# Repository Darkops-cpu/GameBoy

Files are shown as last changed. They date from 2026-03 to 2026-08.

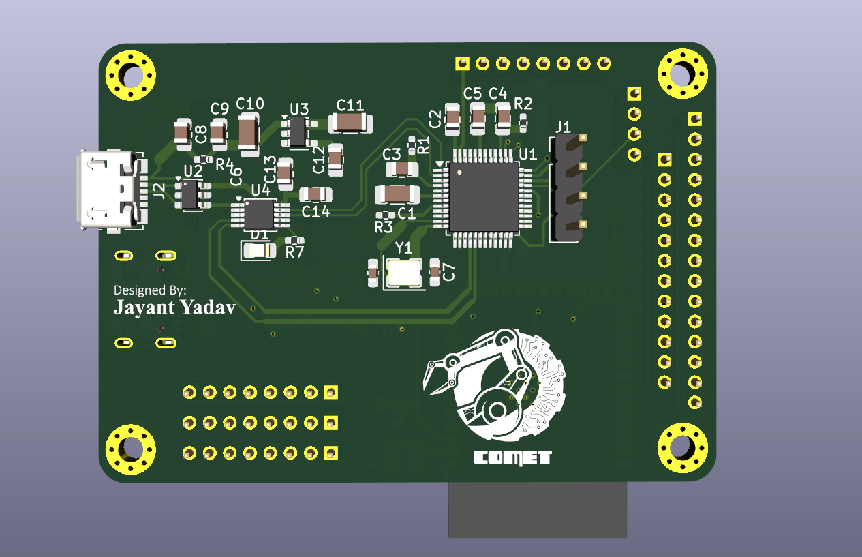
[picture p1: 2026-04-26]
PCB 3D/V2_front.png

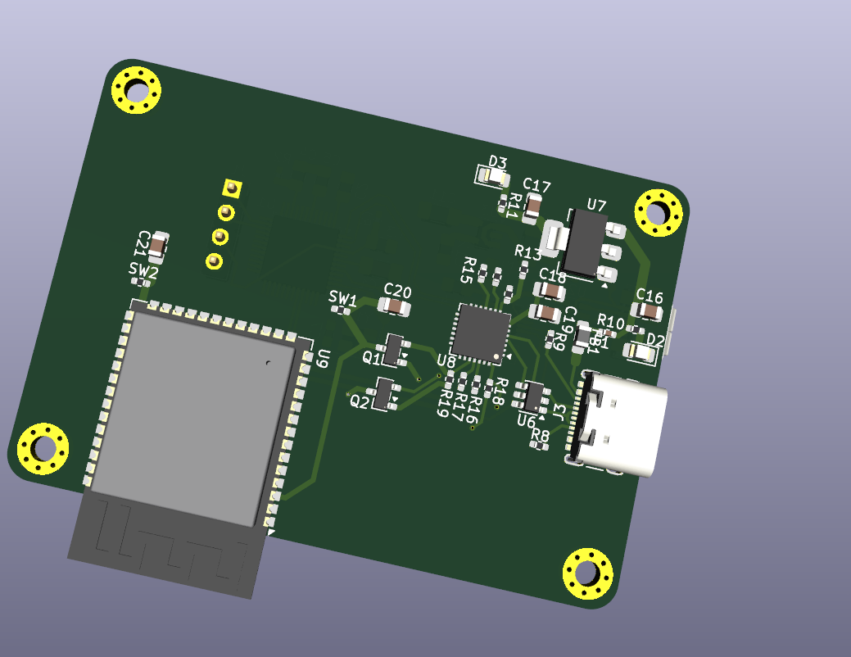
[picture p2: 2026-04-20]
PCB 3D/V1_front.png

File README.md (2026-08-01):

# HADES

 

**An embedded control brain for people who've outgrown the Arduino Uno.**

HADES is a dual-MCU prototyping and control board built around one idea: it is the *brain*, not the *muscle*. It runs your control loops and talks to the network — it does **not** carry motor current. Power for actuators lives on a separate, swappable **HADES shield**, so the brain stays clean, cool, and reusable across every robot you bolt it to.

> **Status:** 🚧 In active design. The architecture below is locked; hardware is in progress. Nothing here is manufactured yet — treat part-specific and pinout details marked _(TBD)_ as not-yet-final.

---

## Table of contents

- [Philosophy: brain, not muscle](#philosophy-brain-not-muscle)
- [Architecture](#architecture)
- [The HADES bus (the shield contract)](#the-hades-bus-the-shield-contract)
- [Planned features](#planned-features)
- [Power](#power)
- [Toolchain & programming](#toolchain--programming)
- [Repository structure](#repository-structure)
- [Getting started](#getting-started)
- [Roadmap](#roadmap)
- [Contributing & succession](#contributing--succession)
- [License](#license)
- [Origin](#origin)

---

## Philosophy: brain, not muscle

Most "do-everything" dev boards try to be the controller *and* the power stage on one PCB. That fights physics: high-current switching, motor back-EMF, heat, and ground bounce all land right next to the quiet analog front-end and the radio that make a good controller good.

HADES refuses that trade. The board sends control signals to the muscle and reads sensors back — nothing more. Actuator power is handled off-board, on a companion shield. The payoff:

- **Clean signals.** The analog front-end and the wireless radio live in a quiet neighborhood.
- **One brain, many muscles.** A small-servo shield today, a brushed-motor shield next term, a big BLDC shield later — same HADES underneath.
- **Failure isolation.** When someone stalls a motor and lets the smoke out of a driver, the cheap shield dies, not the brain.
- **Reusability.** The brain never needs a redesign to drive something new. That work moves to the shield, where it belongs.

## Architecture

HADES pairs a deterministic control MCU with a wireless / compute coprocessor, split by what each is good at.

```
                              HADES (the brain)
   +---------------------------------------------------------------+
   |                                                               |
   |   MSPM0G3507              UART              ESP32-S3 module    |
   |   (master)         <----------------->      (coprocessor)     |
   |   deterministic                              WiFi / BT /      |
   |   control          reset/boot GPIO --->      TinyML           |
   |                                                               |
   +------------------------------[ HADES bus ]--------------------+
                                       |
                                       |  signals + one clean supply
                                       |  (never raw battery / motor current)
                                       v
                              HADES shield (the muscle)
                          power stage / drivers / PDB
                                       |
                                       v
                              motors • servos • ESCs
```

| Role | Part | Handles |
|---|---|---|
| **Master** | TI MSPM0G3507 (Cortex-M0+, 80 MHz) | Deterministic, timing-critical work: control loops, motor PWM, sensor timing, CAN-FD |
| **Coprocessor** | Espressif ESP32-S3 (module) | Non-deterministic work: WiFi/BT, telemetry, OTA, on-device TinyML |

**Why the MSPM0G3507 for control:** two advanced control timers (motor PWM), two simultaneous-sampling 12-bit 4 Msps ADCs plus on-chip op-amps and comparators (a real current-sense front-end), CAN-FD, and the MATHACL trig accelerator to soften the M0+'s lack of a hardware FPU.

**Why the ESP32-S3 for comms/ML:** native USB (clean flashing), WiFi/BT, and vector/SIMD instructions that ESP-NN uses to accelerate TensorFlow Lite Micro — so it does the wireless *and* the on-device ML without a third chip.

The two talk over UART, and the MSPM0 drives the ESP32's `EN`/`IO0` lines so the master can reset or bootload the coprocessor (recovery + firmware updates).

## The HADES bus (the shield contract)

The interface between the brain and its shields is a **frozen, versioned contract** — the most important thing in the whole project. Freeze it well and HADES can rev to v4 while old shields still fit, and a junior can build a brand-new shield for a motor class nobody imagined.

The contract has two halves:

- **Electrical** — a fixed pinout: PWM/servo channels, CAN-FD, I²C, UART, GPIO/ADC breakouts, **one clean regulated supply into the brain**, and reserved lines for **current/voltage-sense telemetry coming back** from the shield (INA-over-I²C style). _(Exact pin assignment: TBD.)_
- **Mechanical** — a fixed board outline, mounting-hole geometry, and stack orientation, so the whole shield family is physically interchangeable. _(Footprint: TBD.)_

**The power boundary is the rule that makes this safe:** across the bus, only signals and one clean supply cross. Raw battery voltage and motor current **never** touch the brain — they stay on the shield.

The contract is versioned independently of the boards (e.g. `HADES bus v1`). A HADES revision and a shield revision each declare which bus version they speak, so compatibility is always unambiguous.

## Planned features

_(Design targets — subject to change until v1 is frozen.)_

- Dual-MCU: MSPM0G3507 master + ESP32-S3 coprocessor over UART
- CAN-FD transceiver + connector (multi-board robots; industry-relevant)
- 3-pin servo/PWM header bank off the MSPM0 advanced timers
- Quadrature encoder inputs on timer channels
- Onboard 6-axis IMU on SPI _(part TBD)_
- Qwiic / STEMMA-QT I²C connector for off-the-shelf sensors
- USB-C on the ESP32-S3 with auto-boot/reset (no button dance to flash)
- SWD header for the MSPM0
- Input protection (reverse-polarity + TVS), per-rail power LEDs, a user LED per MCU
- Test points on every rail and the inter-MCU UART
- Clearly silkscreened, 5 V-tolerant pins marked

## Power

HADES only regulates its *own* clean rails — the muscle's power supply lives on the shield.

- A single step-down stage takes the input down to a 5 V rail; a downstream stage produces 3.3 V for the logic.
- USB-C and the shield-supplied input are OR'd through a priority mux so sources never fight.
- A low-noise LDO (e.g. LT3045-class) generates a separate quiet analog rail for the MSPM0's op-amp/ADC front-end.

The board's own electronics sip very little, so the input battery is sized by whatever the *shield* drives, not by the brain.

## Toolchain & programming

**MSPM0G3507**
- Code Composer Studio + the MSPM0 SDK / DriverLib (or Zephyr / FreeRTOS)
- Flash/debug over SWD with an **XDS110** (e.g. an MSPM0 LaunchPad's onboard probe) or a **CMSIS-DAP** probe via OpenOCD (TI ships `mspm0.cfg`)
- ⚠️ **ST-Link is not supported** — its firmware is locked to STMicroelectronics silicon and will refuse the TI target.

**ESP32-S3**
- ESP-IDF (or Arduino-ESP32)
- Native USB-C — no external programmer needed

## Repository structure

```
hades/
├── hardware/          # KiCad project (schematics, layout, gerbers)
│   ├── hades-brain/   # the main board
│   └── shields/       # HADES shield designs
├── firmware/
│   ├── mspm0/         # master firmware
│   └── esp32s3/       # coprocessor firmware
├── bus-spec/          # the HADES bus contract (pinout + mechanical), versioned
├── docs/              # getting-started, guides, board notes
└── README.md
```

## Getting started

> ⏳ **Coming with the first hardware revision.** Once boards exist, this section will walk you from unboxing to "both MCUs alive, LED blinking, WiFi up" in under an hour. Until then, the design lives under `hardware/` and the interface under `bus-spec/`.

## Roadmap

- [ ] Freeze **HADES bus v1** (pinout + mechanical footprint)
- [ ] Complete the brain schematic and layout (KiCad, 4-layer)
- [ ] Small validation batch (~5 boards) — hand to real users, watch what breaks
- [ ] Getting-started guide + docs
- [ ] First **HADES shield** (matched to the actual motors juniors use)
- [ ] Wider production run

## Contributing & succession

HADES is built to outlive any single maintainer. The project is designed to be handed down: the current maintainer documents it, then passes it to an interested junior with full guidelines, and the cycle continues.

If you're picking this up:
- The **bus spec** is sacred — don't change a frozen bus version; publish a new one.
- Keep the KiCad sources buildable and the docs current; a board nobody can re-order or re-open is a dead board.
- Prefer parts that will still be stockable in two years.

## License

_(To be finalized — recommended split:)_
- **Hardware:** CERN-OHL-S or TAPR OHL
- **Firmware:** MIT or Apache-2.0
- **Documentation:** CC BY 4.0

## Origin

Originally developed at **IIIT Naya Raipur** to give students a genuine step up from the Arduino Uno + ESP32 combo — a real embedded control platform for robotics, maintained and passed down from one cohort to the next.

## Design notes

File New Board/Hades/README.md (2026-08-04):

# HADES

**A dual-MCU control brain for people who've outgrown the Arduino Uno + jumper-wire ESP32 combo.**

HADES is a control board built around one idea: it is the *brain*, not the *muscle*. It runs deterministic control loops and talks to the network — it does **not** carry motor current. Power for actuators lives on a separate, swappable **HADES shield**, so the brain stays clean, cool, and reusable across every robot it gets bolted to.

This repo is also the successor to an earlier, already-taped-out board (internally called **GameBoy**, see [`OLD Board/`](./OLD%20Board)) that proved the dual-MCU concept and is being folded into the brain/shield architecture described here.

> **Status:** 🚧 In active design. `New Board/Hades` is a fresh KiCad 9 project — USB-C input, ESD protection, and power-path parts are placed; the MSPM0/ESP32 core, the bus connector, and the rest of the schematic are not yet drawn. Nothing in this revision is manufactured. Everything marked _(TBD)_ below is not yet final. The **OLD Board** is a finished, previously-fabricated design (schematic + PCB renders present) and is the best current reference for "does this dual-MCU idea actually work."

---

## Table of contents

- [Philosophy: brain, not muscle](#philosophy-brain-not-muscle)
- [Architecture](#architecture)
- [The HADES bus (the shield contract)](#the-hades-bus-the-shield-contract)
- [Planned features](#planned-features)
- [Power](#power)
- [Toolchain & programming](#toolchain--programming)
- [Repository structure](#repository-structure)
- [Current status](#current-status)
- [Lineage: OLD Board (GameBoy) → HADES](#lineage-old-board-gameboy--hades)
- [Getting started](#getting-started)
- [Roadmap](#roadmap)
- [Why this project exists](#why-this-project-exists)
- [Contributing & succession](#contributing--succession)
- [License](#license)
- [Origin](#origin)

---

## Philosophy: brain, not muscle

Most "do-everything" dev boards try to be the controller *and* the power stage on one PCB. That fights physics: high-current switching, motor back-EMF, heat, and ground bounce all land right next to the quiet analog front-end and the radio that make a good controller good.

HADES refuses that trade. The board sends control signals to the muscle and reads sensors back — nothing more. Actuator power is handled off-board, on a companion shield. The payoff:

- **Clean signals.** The analog front-end and the wireless radio live in a quiet neighborhood.
- **One brain, many muscles.** A small-servo shield today, a brushed-motor shield next term, a big BLDC shield later — same HADES underneath.
- **Failure isolation.** When someone stalls a motor and lets the smoke out of a driver, the cheap shield dies, not the brain.
- **Reusability.** The brain never needs a redesign to drive something new. That work moves to the shield, where it belongs.

## Architecture

HADES pairs a deterministic control MCU with a wireless / compute coprocessor, split by what each is good at.

```
                              HADES (the brain)
   +---------------------------------------------------------------+
   |                                                               |
   |   MSPM0G3507              UART              ESP32-S3 module    |
   |   (master)         <----------------->      (coprocessor)     |
   |   deterministic                              WiFi / BT /      |
   |   control          reset/boot GPIO --->      TinyML           |
   |                                                               |
   +------------------------------[ HADES bus ]--------------------+
                                       |
                                       |  signals + one clean supply
                                       |  (never raw battery / motor current)
                                       v
                              HADES shield (the muscle)
                          power stage / drivers / PDB
                                       |
                                       v
                              motors • servos • ESCs
```

| Role | Part | Handles |
|---|---|---|
| **Master** | TI MSPM0G3507 (Cortex-M0+, 80 MHz) | Deterministic, timing-critical work: control loops, motor PWM, sensor timing, CAN-FD |
| **Coprocessor** | Espressif ESP32-S3 (module) | Non-deterministic work: WiFi/BT, telemetry, OTA, on-device TinyML |

**Why the MSPM0G3507 for control:** two advanced control timers (motor PWM), two simultaneous-sampling 12-bit 4 Msps ADCs plus on-chip op-amps and comparators (a real current-sense front-end), CAN-FD, and the MATHACL trig accelerator to soften the M0+'s lack of a hardware FPU.

**Why the ESP32-S3 for comms/ML:** native USB (clean flashing), WiFi/BT, and vector/SIMD instructions that ESP-NN uses to accelerate TensorFlow Lite Micro — so it does the wireless *and* the on-device ML without a third chip.

The two talk over UART, and the MSPM0 drives the ESP32's `EN`/`IO0` lines so the master can reset or bootload the coprocessor (recovery + firmware updates).

## The HADES bus (the shield contract)

The interface between the brain and its shields is a **frozen, versioned contract** — the most important thing in the whole project. Freeze it well and HADES can rev to v4 while old shields still fit, and a junior can build a brand-new shield for a motor class nobody imagined.

The contract has two halves:

- **Electrical** — a fixed pinout: PWM/servo channels, CAN-FD, I²C, UART, GPIO/ADC breakouts, **one clean regulated supply into the brain**, and reserved lines for **current/voltage-sense telemetry coming back** from the shield (INA-over-I²C style). _(Exact pin assignment: TBD.)_
- **Mechanical** — a fixed board outline, mounting-hole geometry, and stack orientation, so the whole shield family is physically interchangeable. _(Footprint: TBD.)_

**The power boundary is the rule that makes this safe:** across the bus, only signals and one clean supply cross. Raw battery voltage and motor current **never** touch the brain — they stay on the shield.

The contract is versioned independently of the boards (e.g. `HADES bus v1`). A HADES revision and a shield revision each declare which bus version they speak, so compatibility is always unambiguous.

## Planned features

_(Design targets — subject to change until v1 is frozen.)_

- Dual-MCU: MSPM0G3507 master + ESP32-S3 coprocessor over UART
- CAN-FD transceiver + connector (multi-board robots; industry-relevant)
- 3-pin servo/PWM header bank off the MSPM0 advanced timers
- Quadrature encoder inputs on timer channels
- Onboard 6-axis IMU on SPI _(part TBD)_
- Qwiic / STEMMA-QT I²C connector for off-the-shelf sensors
- USB-C on the ESP32-S3 with auto-boot/reset (no button dance to flash)
- SWD header for the MSPM0
- Input protection (reverse-polarity + TVS), per-rail power LEDs, a user LED per MCU
- Test points on every rail and the inter-MCU UART
- Clearly silkscreened, 5 V-tolerant pins marked

## Power

HADES only regulates its *own* clean rails — the muscle's power supply lives on the shield.

- A single step-down stage takes the input down to a 5 V rail; a downstream stage produces 3.3 V for the logic.
- USB-C and the shield-supplied input are OR'd through a priority mux so sources never fight.
- A low-noise LDO (e.g. LT3045-class) generates a separate quiet analog rail for the MSPM0's op-amp/ADC front-end.

The board's own electronics sip very little, so the input battery is sized by whatever the *shield* drives, not by the brain.

## Toolchain & programming

**MSPM0G3507**
- Code Composer Studio + the MSPM0 SDK / DriverLib (or Zephyr / FreeRTOS)
- Flash/debug over SWD with an **XDS110** (e.g. an MSPM0 LaunchPad's onboard probe) or a **CMSIS-DAP** probe via OpenOCD (TI ships `mspm0.cfg`)
- ⚠️ **ST-Link is not supported** — its firmware is locked to STMicroelectronics silicon and will refuse the TI target.

**ESP32-S3**
- ESP-IDF (or Arduino-ESP32)
- Native USB-C — no external programmer needed

## Repository structure

This is what's actually in the repo today — not the target layout yet (see [Roadmap](#roadmap) for the reorganization into `hardware/` / `firmware/` / `bus-spec/` once the brain/shield split is real):

```
HADES/
├── New Board/
│   └── Hades/                    # current KiCad 9 project — the HADES "brain" board
│       ├── Hades.kicad_pro
│       ├── Hades.kicad_sch       # schematic (in progress — power in, MCUs not yet placed)
│       ├── Hades.kicad_pcb       # 2-layer layout, early
│       ├── Hades-backups/        # KiCad auto-backups (timestamped .zip snapshots)
│       └── README.md
├── OLD Board/                    # predecessor design, "GameBoy" — finished, previously fabricated
│   ├── README.md                 # full spec sheet + design-decision rationale
│   ├── Schematic/                # V1.0 – V1.3 schematic PDFs
│   ├── Docs/                     # V1.0 – V1.3 per-revision changelogs
│   ├── PCB 3D/                   # rendered board images (front/back, V1 & V2)
│   └── Reference/                # ESP32/MSPM0 datasheets + design references
└── README.md                     # this file
```

## Current status

| Track | State |
|---|---|
| **OLD Board (GameBoy)** — architecture proof | ✅ Schematic finalized through V1.3, PCB rendered, previously fabricated |
| **New Board (HADES brain)** — schematic | 🔄 Power input (USB-C, ESD protection) placed; MSPM0G3507 + ESP32-S3 core not yet drawn |
| **New Board (HADES brain)** — layout | 🔄 2-layer board started; routing pending schematic completion |
| **HADES bus (shield contract)** | ⏳ Not yet frozen — pinout and mechanical footprint TBD |
| **HADES shield** | ⏳ Not started |
| **Firmware (either MCU)** | ⏳ Not started — waiting on hardware |

## Lineage: OLD Board (GameBoy) → HADES

The `OLD Board/` design (codename **GameBoy**, no relation to Nintendo) is where the dual-MCU idea — TI **MSPM0G3507** as the deterministic master, **ESP32-S3-WROOM-1** as the wireless/compute coprocessor over UART — was designed, schematic-captured, and taken through four documented revisions:

| Rev | Change | Why |
|---|---|---|
| V1.0 | Single MCU (MSPM0G3507) + CH340E debug UART + LIS2DH accelerometer | Baseline: get the master MCU alive and talking |
| V1.1 | Added ESP32-S3-WROOM-1 coprocessor, CP2102N + auto-boot circuit, USB-C | Wireless/compute half of the architecture, flashable without a button dance |
| V1.2 | Added TP4056 Li-ion charging + BJT/MOSFET power-path switching | Untethered, battery-capable operation |
| V1.3 | **Removed** the V1.2 battery circuitry | Simplify the power path for the current build phase — a real "found the hard way, fixed" cycle, not just additive changes |

That revision history is the same succession pattern this repo is designed to keep running: something breaks or turns out unnecessary, the next revision documents why and fixes it, and the fix is traceable in `OLD Board/Docs/`.

`New Board/Hades` is the next link in that chain — it keeps the dual-MCU pairing but re-architects around the **brain/shield split** described above, instead of putting motor drive and battery management on the same board as the control MCU.

## Getting started

> ⏳ **Coming with the first hardware revision.** Once brain boards exist, this section will walk you from unboxing to "both MCUs alive, LED blinking, WiFi up" in under an hour, with no hand-wired jumper diagram involved. Until then:
> - To see the dual-MCU architecture working end-to-end today, read [`OLD Board/README.md`](./OLD%20Board/README.md) and the V1.0–V1.3 docs in [`OLD Board/Docs/`](./OLD%20Board/Docs).
> - To follow or contribute to the current board, open [`New Board/Hades/Hades.kicad_sch`](./New%20Board/Hades/Hades.kicad_sch) in KiCad 9.

## Roadmap

- [ ] Complete the HADES brain schematic (MSPM0G3507 + ESP32-S3 core, current-sense front-end, CAN-FD transceiver)
- [ ] Freeze **HADES bus v1** (pinout + mechanical footprint)
- [ ] Finish the 4-layer brain PCB layout
- [ ] Small validation batch (~5 boards) — hand to real users, watch what breaks
- [ ] Reorganize the repo into `hardware/` / `firmware/` / `bus-spec/` / `docs/` once the brain/shield split is fabricated
- [ ] Getting-started guide + docs (the "forty minutes to a sweeping servo" experience)
- [ ] First **HADES shield** (matched to the actual motors used on club robots)
- [ ] Wider production run + institutional handoff to a junior maintainer

## Why this project exists

The measure of success here isn't the PCB — it's what happens after it. HADES is meant to stop being "someone's project" and become "the board": something a first-year reaches for in week three without a wiring diagram, something the club's competition robots run on under real deadline pressure, something that keeps getting revised by people who never met the original designer.

Concretely, that means:
- **Faster than the breadboard, not just different from it.** If reaching for a HADES isn't the obviously easier choice next to a fistful of dupont wires, the board hasn't earned its place yet.
- **Survives contact with students and with robots.** Bench demos are cheap; a board holding a current-sense loop through a stalled motor for real, under competition deadline, is the actual test.
- **The revision chain has to turn without the original designer.** Rev 1 will have a quirk someone finds the hard way (the OLD Board's V1.0→V1.3 history is exactly that pattern already). What matters is whether rev 2 gets fixed and shipped by someone else, using docs good enough that they didn't need to ask.

Almost every student hardware project dies on two things: **documentation nobody wrote** and **a handoff that never happened**. Everything in [Contributing & succession](#contributing--succession) below exists to clear those two bars on purpose, rather than assuming they'll clear themselves.

## Contributing & succession

HADES is built to outlive any single maintainer. The project is designed to be handed down: the current maintainer documents it, then passes it to an interested junior with full context, and the cycle continues — the same way `OLD Board/Docs/V1.0.md` through `V1.3.md` already document what changed and why at each step.

If you're picking this up:
- The **bus spec** is sacred — don't change a frozen bus version; publish a new one.
- Keep the KiCad sources buildable and the docs current; a board nobody can re-order or re-open is a dead board.
- Document *why*, not just *what* — follow the pattern in `OLD Board/Docs/`: what changed, and the reason, per revision.
- Prefer parts that will still be stockable in two years.
- If you're the one stepping back, name your successor before you go quiet — a maintainer chain with a gap in it is how projects die.

## License

_(To be finalized — recommended split:)_
- **Hardware:** CERN-OHL-S or TAPR OHL
- **Firmware:** MIT or Apache-2.0
- **Documentation:** CC BY 4.0

## Origin

Originally developed at **IIIT Naya Raipur** to give students a genuine step up from the Arduino Uno + ESP32 combo — a real embedded control platform for robotics, maintained and passed down from one cohort to the next.

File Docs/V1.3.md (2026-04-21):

# Schematic V1.3 Documentation

## 1. Overview
The V1.3 board keeps the dual-processor architecture (MSPM0G3507SPTR and ESP32-S3 WROOM 1) while removing the battery charging and battery switching/load-sharing circuitry introduced previously. This revision returns the design to a wired-power-only approach and simplifies the power path for the current build phase.

## 2. Core Components
The main processing and connectivity elements remain unchanged:
- **Primary Microcontroller (MCU):** Texas Instruments MSPM0G3507SPTR.
- **Secondary Microcontroller:** **ESP32-S3 WROOM 1** module.
- **Inter-Processor Bridge:** Communication bridge between MSPM0 and ESP32 is established.
- **USB-to-UART Controller:** CP2102N for serial communication and ESP32 auto-boot support.
- **Accelerometer:** LIS2DH for motion sensing.

## 3. Power Subsystem (Revision Change)
The V1.3 power subsystem removes all battery-management-specific blocks:
- **Removed:** Li-ion charging circuit.
- **Removed:** Battery switching/load-sharing circuit.
- **System Power:** Board is powered from USB input and regulated to 3.3V through the **LM1117** linear regulator.

## 4. Interfaces and Connectors
- **USB Interface:** USB-C receptacle for power and data.
- **ESP32 Auto-Boot:** DTR/RTS auto-boot circuitry retained.
- **Battery Interface:** No battery charging or battery switching path in this revision.

## 5. Status, Flashing, and Errata
- **Schematic Status:** Finalized for PCB plotting.
- **Flashing:**
	- ESP32-S3 programs via USB-C using the CP2102N auto-boot circuit.
	- MSPM0 requires an **ST-Link** (or compatible SWD programmer).
- **Errata:** No known issues documented for V1.3 at this time.

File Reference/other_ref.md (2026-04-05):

## Other References

- Stack Exchange: [link](https://electronics.stackexchange.com/questions/21570/switch-between-battery-and-usb-power)
- GitHub: [link](https://github.com/alltheworld/tp4056)
- Espressif Guidelines: [link](https://docs.espressif.com/projects/esp-hardware-design-guidelines/en/latest/esp32/pcb-layout-design.html)

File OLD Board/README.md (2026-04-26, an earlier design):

# GameBoy 🎮


A custom dual-processor embedded development platform built around the **Texas Instruments MSPM0G3507** and the **Espressif ESP32-S3-WROOM-1**, designed for IoT connectivity, sensor data collection, and general-purpose prototyping.

> Designed from scratch in KiCad 9.0.8 — schematic complete, PCB layout in progress.

## Project Summary

GameBoy is a dual-MCU embedded platform that combines the real-time control of the MSPM0G3507 with the wireless connectivity of the ESP32-S3-WROOM-1. The board uses a dedicated UART bridge between the two processors, includes onboard programming and debug interfaces, and is being developed as a compact hardware platform for prototyping, sensor integration, and IoT-oriented experiments. The current revision is a 4-layer board to support cleaner routing, better power integrity, and improved overall layout density.

---

## Overview

GameBoy is a compact, battery-capable development board that pairs the real-time processing power of the MSPM0G3507 with the WiFi and Bluetooth capabilities of the ESP32-S3, communicating over a dedicated UART bus. The goal is a flexible platform that can be adapted across a wide range of embedded applications without redesigning hardware each time.

This is not a hobbyist shield or a breakout board. Every subsystem — power architecture, programming interfaces, peripheral connections, and RF considerations — has been designed with deliberate engineering decisions documented below.

---

## Hardware Specifications

| Parameter | Details |
|---|---|
| Main MCU | TI MSPM0G3507SPTR — ARM Cortex-M0+, 80MHz, 128KB Flash, 32KB SRAM |
| Co-processor | Espressif ESP32-S3-WROOM-1 — Xtensa LX7, WiFi 802.11 b/g/n, BLE 5.0 |
| Inter-processor bus | UART (MSPM0 UART1 ↔ ESP32-S3 UART0) |
| Supply voltage | 5V via USB / Single-cell Li-ion (18650) |
| System voltage | 3.3V (SPX3819M5 LDO) |
| Battery charging | MCP73831 linear charger — 300mA via USB-C |
| Power path | LM66200DRLR ideal diode — automatic USB / battery switchover |
| Crystal | 8MHz external oscillator for MSPM0 |
| PCB layers | 4-layer |
| EDA tool | KiCad 9.0.8 |

---

## Block Diagram

```
                        ┌─────────────────────────────────────┐
                        │           Power Section             │
  USB-C (5V) ──────────►│ MCP73831 ──► 18650 Li-ion           │
                        │ LM66200 (auto power path switching)  │
                        │ SPX3819M5 LDO ──► 3.3V rail         │
                        └────────────────┬────────────────────┘
                                         │ 3.3V
                  ┌──────────────────────┼──────────────────────┐
                  │                      │                      │
         ┌────────▼────────┐    ┌────────▼────────┐   ┌────────▼────────┐
         │  MSPM0G3507     │    │  ESP32-S3        │   │  LIS2DH12       │
         │  Main processor │◄──►│  WiFi + BT       │   │  Accelerometer  │
         │  SWD via STLink │UART│  CP2102N + auto  │   │  SPI            │
         │  UART0 debug    │    │  boot circuit    │   └─────────────────┘
         └────────┬────────┘    └────────┬─────────┘
                  │                      │
         ┌────────▼────────┐    ┌────────▼─────────┐
         │  GPIO Bank A    │    │  GPIO Bank B      │
         │  MSPM0 pins     │    │  ESP32-S3 pins    │
         └─────────────────┘    └──────────────────┘
```

---

## Subsystems

### Main MCU — MSPM0G3507
- ARM Cortex-M0+ running at up to 80MHz
- Programmed via SWD using STLink V2 through a 4-pin header (SWCLK, SWDIO, NRST, GND)
- UART0 exposed via onboard CH340E for debug output
- 4 UART peripherals available — UART1 dedicated to ESP32-S3 communication
- Full GPIO bank broken out to 2.54mm headers

### Co-processor — ESP32-S3-WROOM-1
- Handles all WiFi and Bluetooth stack operations
- Programmed independently via dedicated USB-C port and CP2102N USB-UART bridge
- Auto-boot circuit (two MMBT2222A NPN transistors) — no manual button pressing required to flash
- Manual reset (SW1) and boot (SW2) buttons included as fallback
- IO19 and IO20 (native USB D+/D−) left available for future USB device applications
- GPIO bank broken out to 2.54mm headers

### Power Architecture
- **LM66200DRLR** ideal diode controller manages automatic switchover between USB-C (5V) and Li-ion battery (3.7V) — USB always takes priority when present
- **MCP73831** linear charger handles single-cell Li-ion charging at 300mA (set via 3.3K RPROG resistor), powered from the ESP32-S3 USB-C port
- **SPX3819M5** 500mA LDO regulates system 3.3V rail
- Two 18650 cells in parallel supported — no balancing circuit required for parallel configuration
- Battery voltage monitoring via MSPM0 ADC through resistor divider

### Programming Interfaces
| Target | Method | Connector |
|---|---|---|
| MSPM0G3507 firmware | STLink V2 via SWD | 4-pin header |
| MSPM0 debug UART | CH340E via USB Micro | USB Micro B |
| ESP32-S3 firmware | CP2102N + auto-boot via USB-C | USB-C |

### Peripheral — LIS2DH12 Accelerometer
- ST MEMS 3-axis accelerometer
- Connected via SPI to MSPM0G3507
- INT1 and INT2 interrupt lines routed to MSPM0 GPIO

---

## Repository Structure

```
GameBoy/
├── Schematic/
│   ├── V1.0.pdf          # Main MCU schematic sheet
│   ├── V1.0.pdf         # Main MCU schematic sheet + ESP32-S3 subcircuit sheet
├── Docs/
│   └── esp32_devkitc_v4-sch.pdf        # ESP32 Device schematic reference
|   └── mspm0g3507_Ti.pdf       # MSPM0 Instruction Manual
├── Docs/
│   ├── V1.0.md/                     # upadtes implemented in schematic one
│   └── V2.0.md/                     # updates implemented in schematic two
└── README.md
```

---

## Design Decisions

A few non-obvious decisions made during the design process, documented for anyone reading the schematic.

**Why MSPM0G3507 and not STM32?**
TI's MSPM0 series offers a competitive Cortex-M0+ core with a generous free tier on Code Composer Studio and strong documentation. The LQFP-48 package is hand-solderable and the peripheral set covers everything needed for this platform.

**Why ESP32-S3 and not classic ESP32?**
The S3 supports BLE 5.0 and has a native USB peripheral on IO19/IO20, keeping future options open. The WROOM-1 module handles the RF design, antenna matching, and FCC certification — removing the most complex part of ESP32 integration from the custom PCB.

**Why CP2102N for ESP32 programming instead of using native USB?**
Native USB on IO19/IO20 works, but is dependent on the ESP32-S3 firmware being functional. A dedicated CP2102N with auto-boot circuit means the programming interface is always independent of firmware state — critical on a prototyping board where firmware is frequently broken during development.

**Why 4-layer PCB?**
The 4-layer stackup improves power distribution, signal routing, and ground integrity for the dual-MCU design. It also gives cleaner separation between noisy digital sections, the ESP32-S3 RF area, and the power subsystem while making the board easier to route at the current feature density.

**Why LM66200 for power path instead of a discrete P-FET?**
The LM66200 is an ideal diode controller with 40mΩ on-resistance, automatic priority switching, reverse current blocking, and 1.32µA quiescent current — all in one IC with no external switching logic required. The discrete P-FET approach requires careful gate biasing and does not block reverse current.

---

## Current Status

| Milestone | Status |
|---|---|
| System architecture | ✅ Complete |
| MSPM0 schematic | ✅ Complete |
| ESP32-S3 schematic | ✅ Complete |
| Power section schematic | ✅ Complete |
| PCB layout | 🔄 In progress |
| Fabrication | ⏳ Pending layout |
| Firmware — MSPM0 | ⏳ Pending hardware |
| Firmware — ESP32-S3 | ⏳ Pending hardware |

---

## Planned Features (Future Revisions)

- Motor driver header with PWM breakout from MSPM0 timers
- QWIIC / Stemma QT I2C connector for plug-and-play sensor expansion
- USB-C PD negotiation for faster battery charging
- Onboard LiPo fuel gauge IC for accurate battery percentage reporting
- KiCad PCB layout with JLCPCB-compatible BOM and CPL files

---

## Tools Used

- **KiCad 9.0.8** — schematic capture and PCB layout
- **Code Composer Studio** — MSPM0 firmware development
- **ESP-IDF** — ESP32-S3 firmware development
- **LCSC** — component sourcing

---

## Author

Darkops-CPU (Jayant Yadav)

---

*The name GameBoy has no relation to Nintendo's product. It is an arbitrary project codename.*

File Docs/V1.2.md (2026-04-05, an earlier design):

# Schematic V1.2 Documentation

## 1. Overview
The V1.2 board builds upon the dual-processor architecture of V1.1 (MSPM0G3507SPTR and ESP32-S3 WROOM 1) by introducing full battery power management. This revision features a dedicated Li-ion battery charging and discharging circuit, alongside an automatic power switching mechanism to allow the board to function seamlessly when plugged into USB or running directly off the battery. The schematic is finalized and ready for PCB plotting.

## 2. Core Components
The primary processing and connectivity components are carried over from V1.1:
- **Primary Microcontroller (MCU):** Texas Instruments MSPM0G3507SPTR.
- **Secondary Microcontroller:** **ESP32-S3 WROOM 1** module.
- **Inter-Processor Bridge:** The bridge between the MSPM0 and ESP32 has been established.
- **USB-to-UART Controller:** CP2102N for serial communication and debugging with auto-boot support for the ESP32.
- **Accelerometer:** LIS2DH for motion sensing.

## 3. Power Subsystem (Major Update)
The V1.2 revision completely revamps the power subsystem to support untethered operation:
- **Battery Specifications:** Designed for a standard Li-ion battery.
- **Charging Circuit:** Utilizes a standard TP4056-based charging circuit to safely charge the Li-ion battery when USB-C is connected.
- **Power Switching/Load Sharing:** An automatic power-path switching circuit has been implemented using a combination of two BJTs (NPN and PNP) and one P-Channel MOSFET. This ensures that when the USB-C is connected, the system is powered directly from USB while the battery charges, and when disconnected, it transitions smoothly to battery power without interrupting the processors.
- **System Power:** The board continues to use the **LM1117** linear regulator (carried from V1.1) to provide a stable 3.3V supply to the MCUs from either the battery or USB source.

## 4. Interfaces and Connectors
- **Battery Connector:** A terminal block has been added to securely connect the Li-ion battery to the power management circuit.
- **USB Interface:** USB-C receptacle for data and power delivery/charging.
- **ESP32 Auto-Boot:** Retains the DTR/RTS auto-boot circuitry for the ESP32-S3.

## 5. Known Issues, Flashing, and Errata
- **Flashing:** 
  - ESP32-S3 programs via the USB-C port utilizing the CP2102N auto-boot circuit.
  - MSPM0 still requires an **ST-Link** (or compatible SWD programmer) for flashing.
- **Errata:** There are currently no known issues or errata documented for the V1.2 release.

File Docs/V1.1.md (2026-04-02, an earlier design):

# Schematic V1.1 Documentation



## 1. Overview
The V1.1 board builds upon the initial design by introducing a dual-processor architecture. It retains the core processing capabilities while adding an ESP32-S3 WROOM 1 module to handle advanced connectivity and secondary processing tasks.

## 2. Core Components
Significant updates have been made to the component selection in this revision:
- **Primary/Secondary Microcontrollers:** 
  - The board now features an **ESP32-S3 WROOM 1** module as a secondary processor for enhanced capabilities and wireless communication.
  - (Assuming retention of the original MSPM0G3507SPTR main MCU and LIS2DH accelerometer from V1.0, unless otherwise replaced).
- **USB-to-UART Controller:** Upgraded to the **CP2102N**, providing robust serial communication and debugging, specifically supporting the new ESP32 integration.
- **Clocking:** Relevant crystal oscillators for both MCUs.

## 3. Power Subsystem
The power architecture has been modernized for better compatibility and current delivery:
- **Power Input:** Upgraded to **USB-C** for both power delivery and data connection.
- **Voltage Regulation (LDO):** The primary 3.3V power supply is now driven by an **LM1117** linear regulator to meet the increased current demands of the ESP32-S3.

## 4. Interfaces, Connectors, and Boot Logic
While external displays or heavy peripherals are still omitted in this revision, crucial interface updates have been made:
- **ESP32 Auto-Boot:** The integration of an auto-boot circuit for the ESP32-S3 has been enabled, allowing for seamless programming and resetting without manual button presses via the CP2102N UART lines (DTR/RTS).
- **USB Interface:** Modern USB-C receptacle replaces the older Micro USB.

## 5. Known Issues, Flashing, and Errata
- **Flashing the ESP32-S3:** The auto-boot circuitry handles putting the ESP32-S3 into the correct boot mode automatically during programming.
- **Flashing the MSPM0:** The original requirement of using an **ST-Link** (or compatible SWD programmer) via the SWD interface remains unchanged from V1.0.
- **Errata:** There are currently no known bugs or errata documented for the V1.1 release.

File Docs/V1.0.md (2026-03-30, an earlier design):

# Schematic V1.0 Documentation



## 1. Overview
The V1.0 board serves as the main processor module for the overarching design. It handles the core logic, processing, and acts as the central hub before integration with the rest of the hardware components.

## 2. Core Components
The board integrates several key components to achieve its processing and connectivity goals:
- **Main Microcontroller (MCU):** Texas Instruments `MSPM0G3507SPTR` in a 48-LQFP package.
- **USB-to-UART Controller:** `CH340E` for serial communication and debugging.
- **Accelerometer:** `LIS2DH` for motion sensing and orientation detection.
- **Clock:** 8MHz external crystal oscillator for precise timing.

## 3. Power Subsystem
The power architecture is designed to step down a standard 5V USB input to the 3.3V logic level required by the MCU and peripherals.
- **Power Input:** Micro USB (5V source).
- **ESD Protection:** `USBLC6-2SC6` on the USB D+/D- lines to protect against electrostatic discharge.
- **Voltage Regulation (LDO):** `SPX3819M5-L-3-3` Low Dropout Regulator to provide a stable 3.3V supply to the system.

## 4. Interfaces and Connectors
As of V1.0, the primary interface is the Micro USB port for power and UART communication. Other external user interfaces (such as screens or buttons) are currently omitted on this revision and will be included once the board is fully integrated into the larger chassis/design.

## 5. Known Issues, Flashing, and Errata
> **Warning: Programming Interface**
> The only significant caveat in this revision involves the programming process. If not done correctly, the board will fail to program.
> - An **ST-Link** (or compatible SWD programmer) is required to flash the `MSPM0G3507SPTR` microcontroller.
> - Ensure proper SWD (Serial Wire Debug) connections (SWDIO, SWCLK, GND, 3V3) are made from the ST-Link to the corresponding pins/pads on the board.

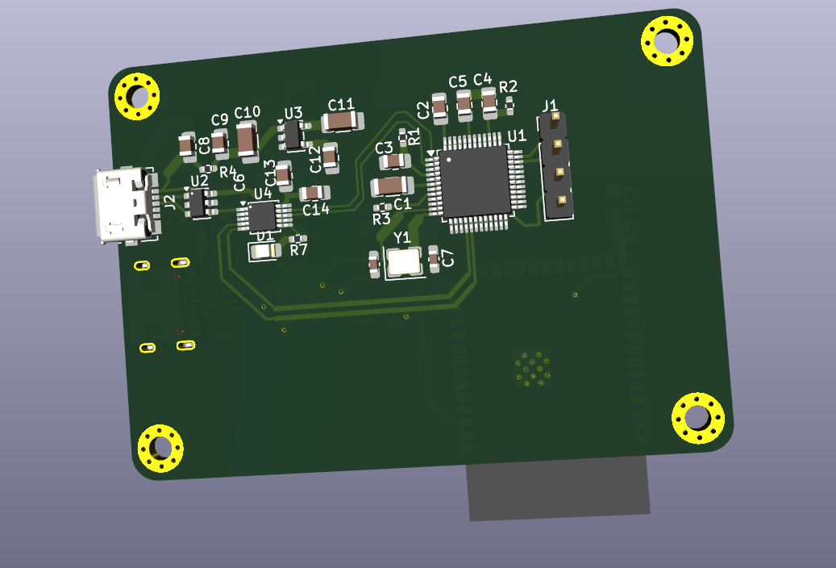
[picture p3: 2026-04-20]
PCB 3D/V1_back.png

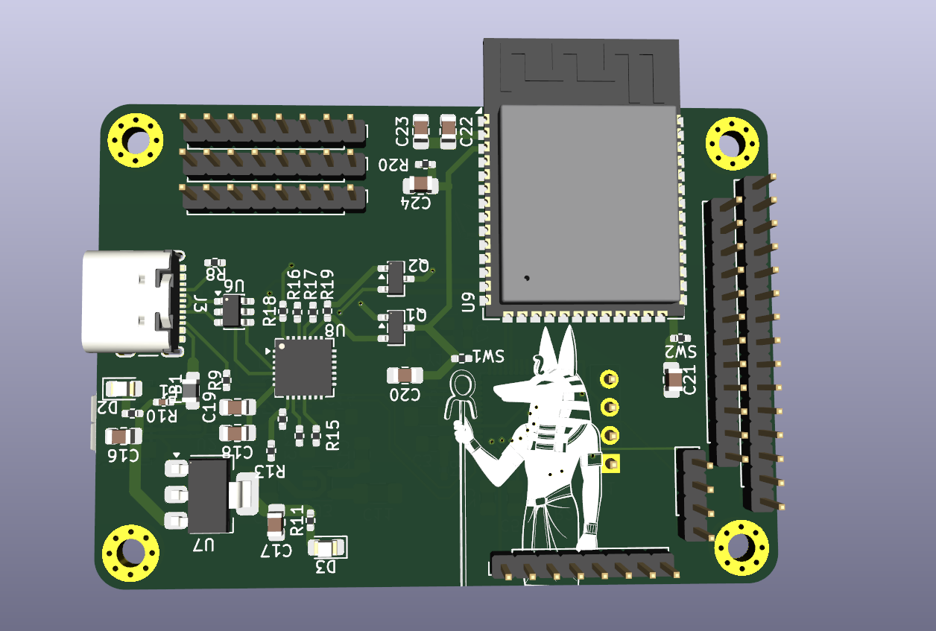
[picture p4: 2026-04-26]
PCB 3D/V2_back.png

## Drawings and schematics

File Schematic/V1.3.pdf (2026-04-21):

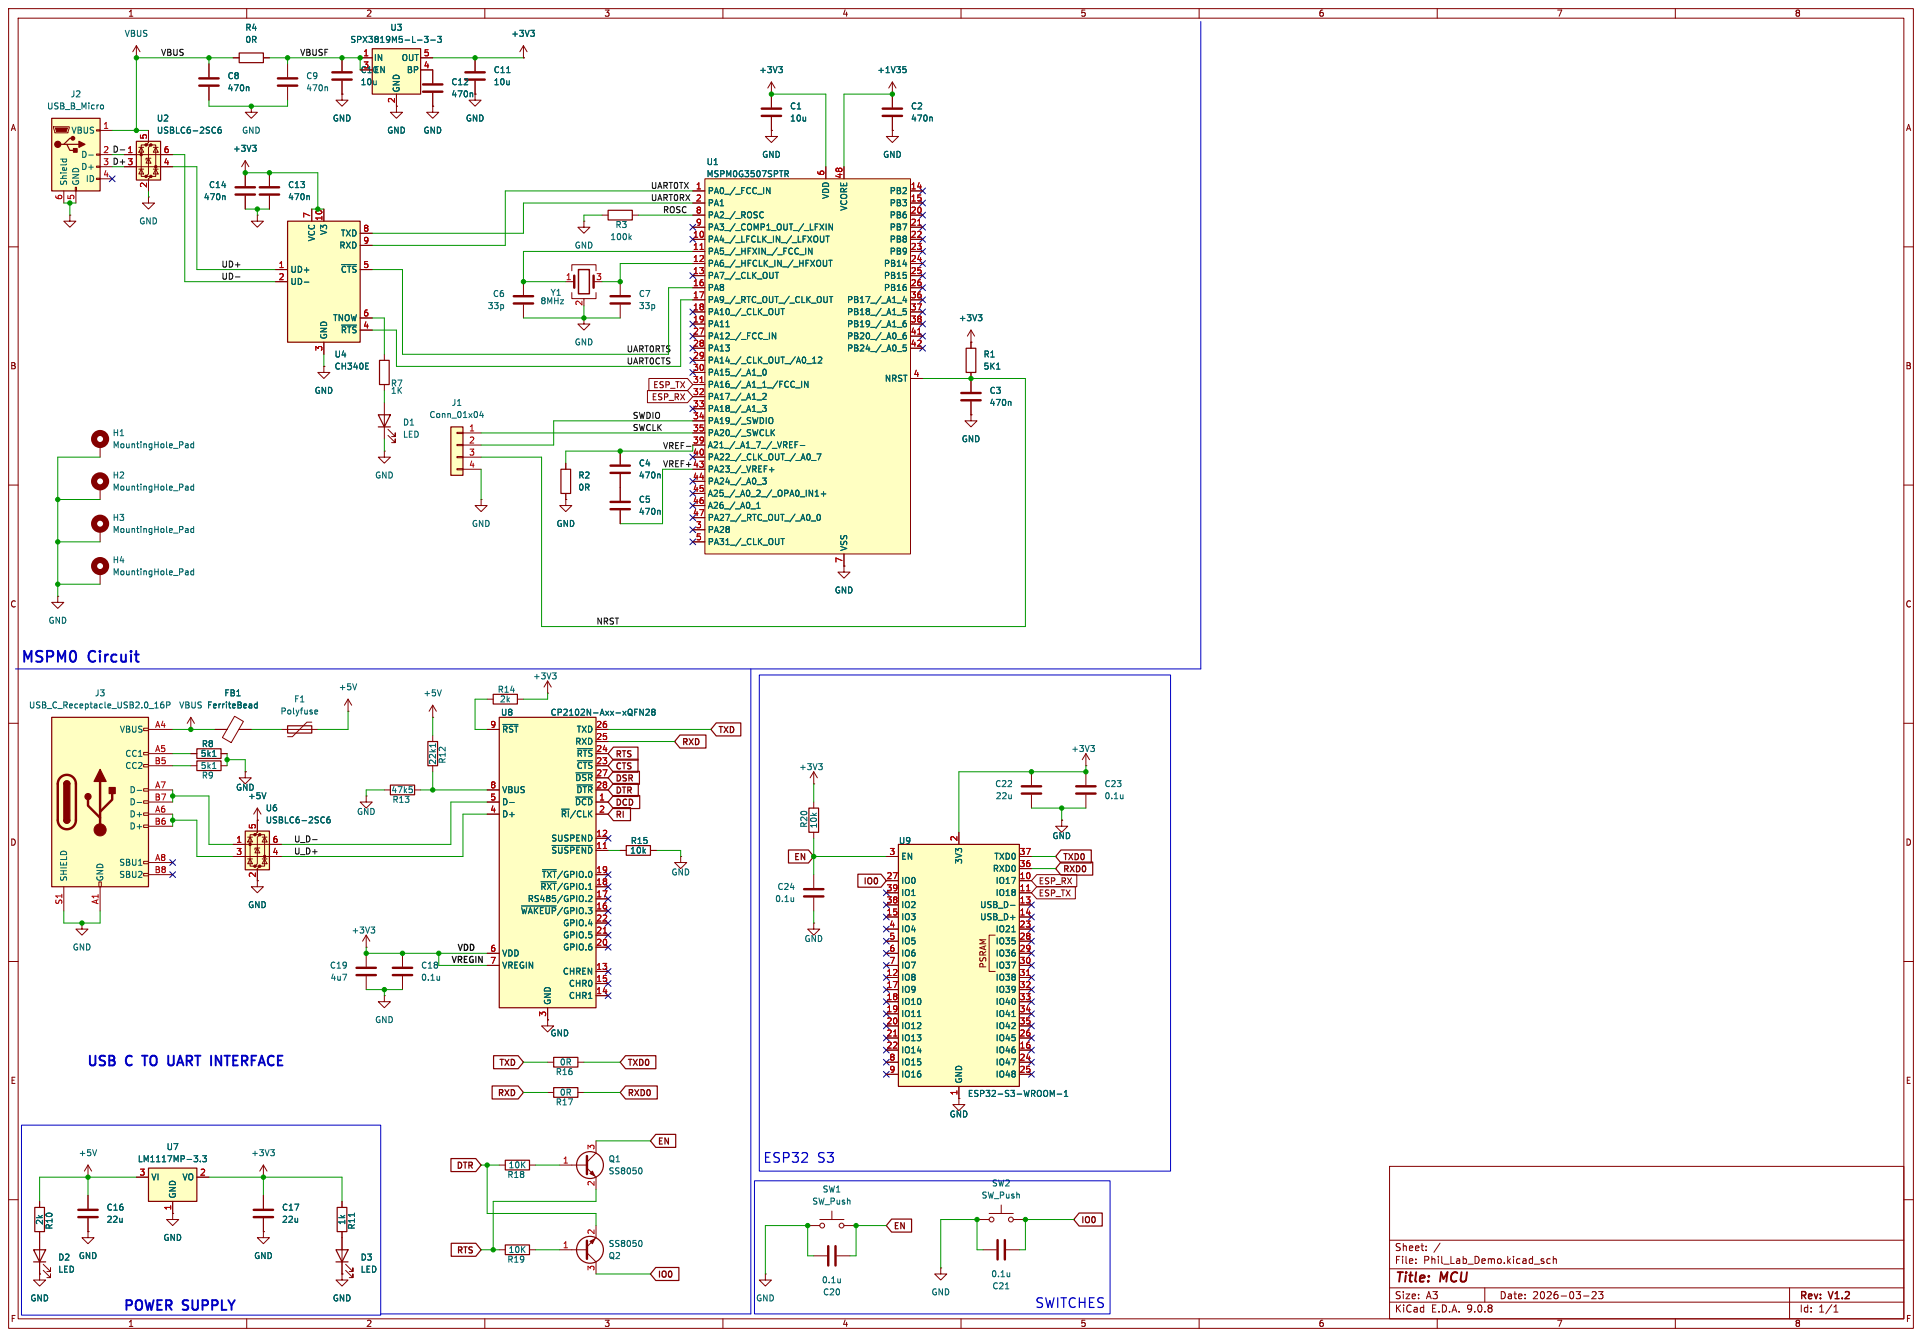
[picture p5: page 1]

USB C TO UART INTERFACE

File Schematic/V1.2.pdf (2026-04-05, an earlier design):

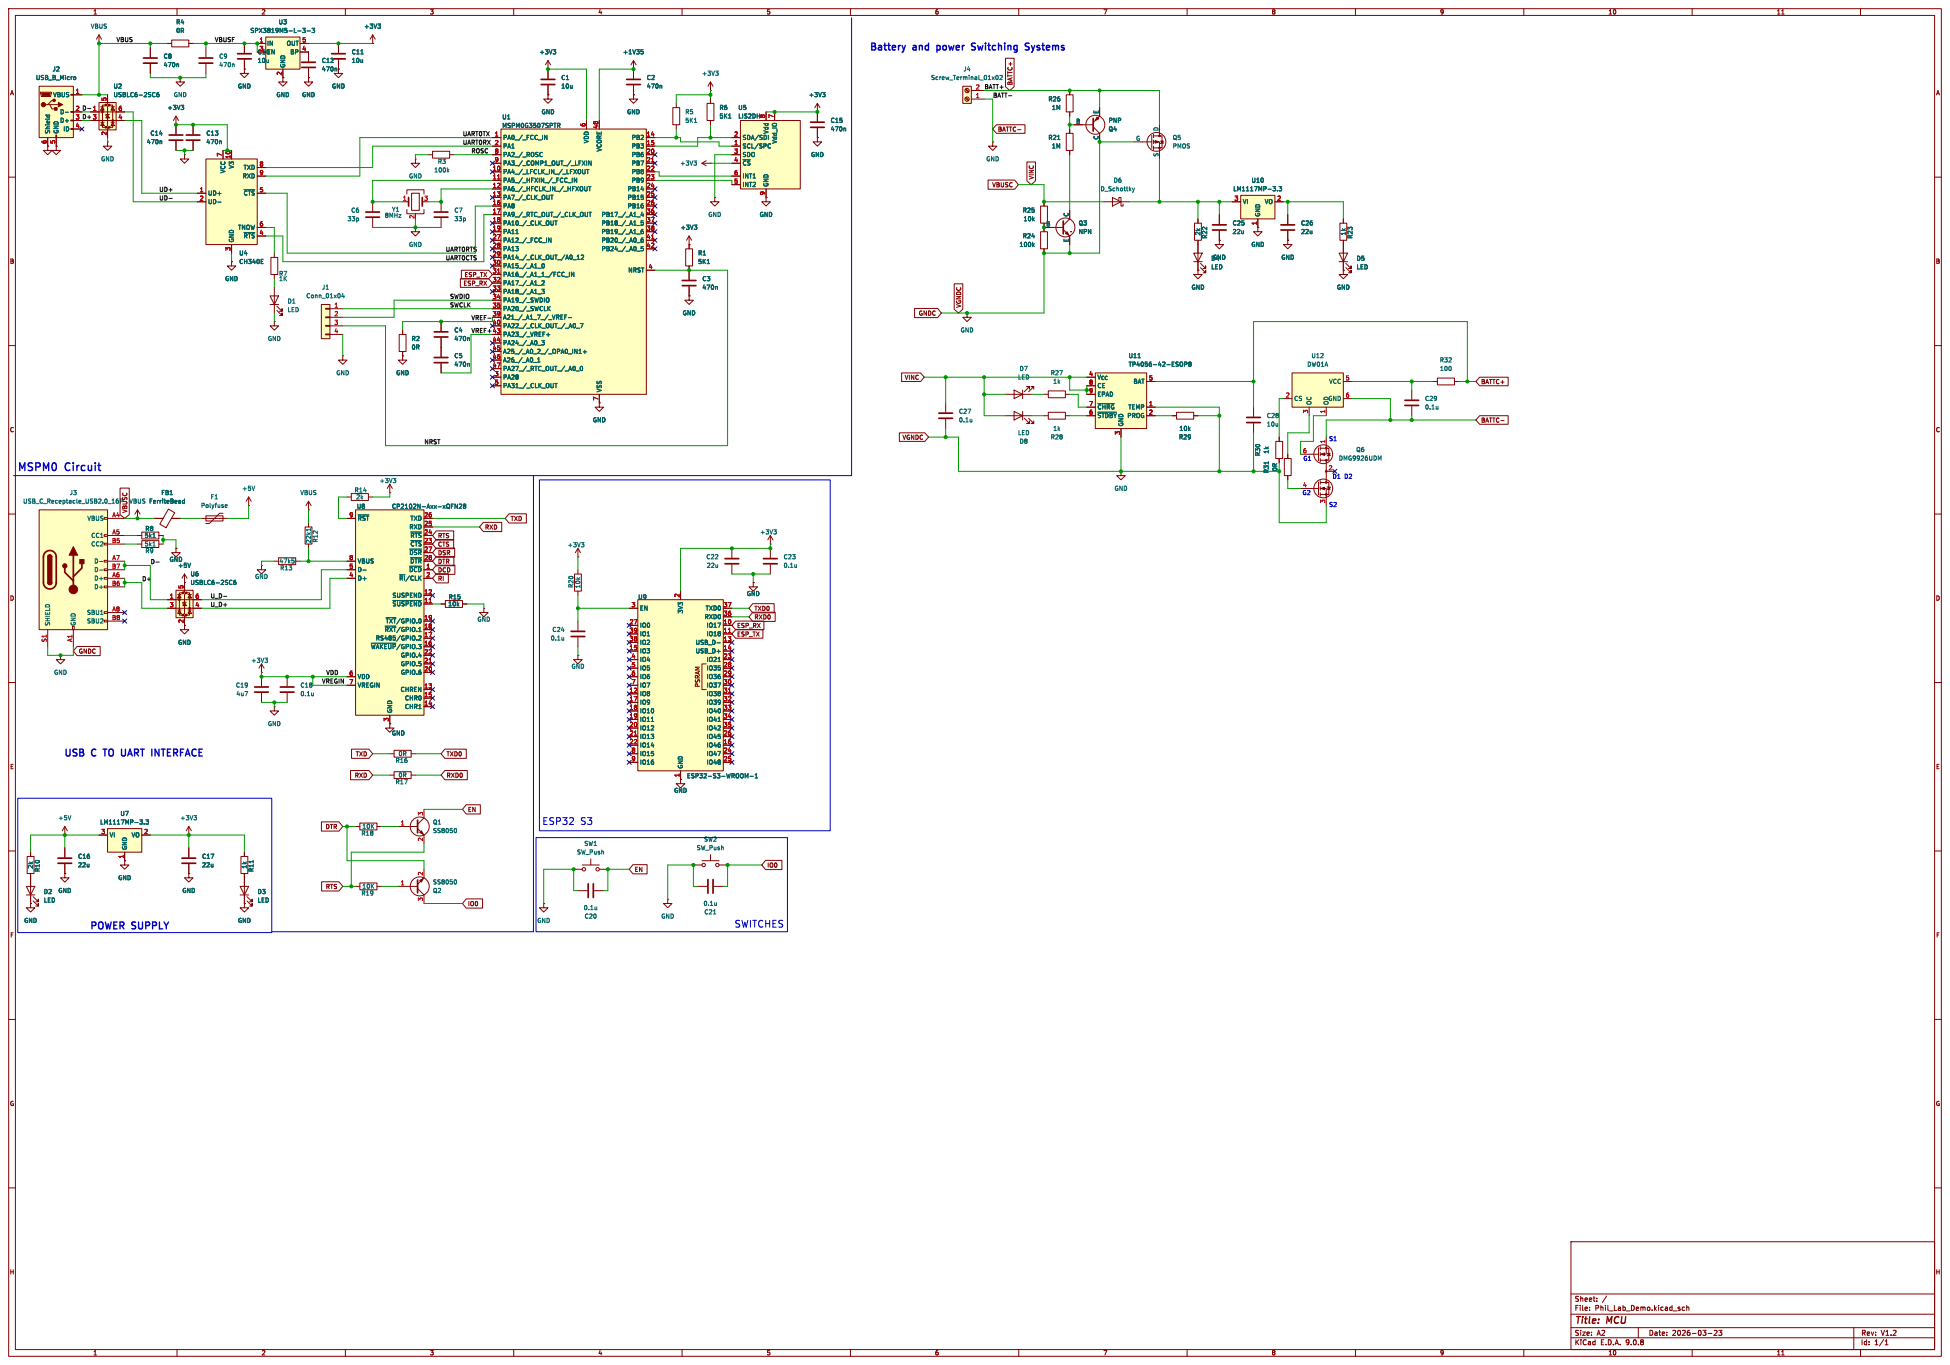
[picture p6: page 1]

2 OUT 5 BP 4 U3 SPX3819M5-L-3-3 GND GND GND

Battery and power Switching Systems

3 TXD 8 RXD 9 ~{CTS}5 TNOW 6 ~{RTS}4 U4 CH340E

3 TXD 8 RXD 9 ~{CTS}5 TNOW 6 ~{RTS}4 R30 1k R31 0R

3 BAT 5 TEMP 1 PROG 2 U11 TP4056-42-ESOP8 R23 1k GND

G1 USB C TO UART INTERFACE

3 TXD 26 RXD 25 ~{RTS} 24 ~{CTS} 23 ~{DSR} 27 ~{DTR} 28 ~{DCD}1 ~{RI}/CLK2 SUSPEND 12 ~{SUSPEND}11 ~{TXT}/GPIO.019 ~{RXT}/GPIO.118 RS485/GPIO.2 17 ~{WAKEUP}/GPIO.316 GPIO.4 22 GPIO.5 21 GPIO.6 20 CHREN 13 CHR0 15 CHR1 14 U8 CP2102N-Axx-xQFN28 +3V3 GND

3 TXD 26 RXD 25 ~{RTS} 24 ~{CTS} 23 ~{DSR} 27 ~{DTR} 28 ~{DCD}1 ~{RI}/CLK2 SUSPEND 12 ~{SUSPEND}11 ~{TXT}/GPIO.019 ~{RXT}/GPIO.118 RS485/GPIO.2 17 ~{WAKEUP}/GPIO.316 GPIO.4 22 GPIO.5 21 GPIO.6 20 CHREN 13 CHR0 15 CHR1 14 R15

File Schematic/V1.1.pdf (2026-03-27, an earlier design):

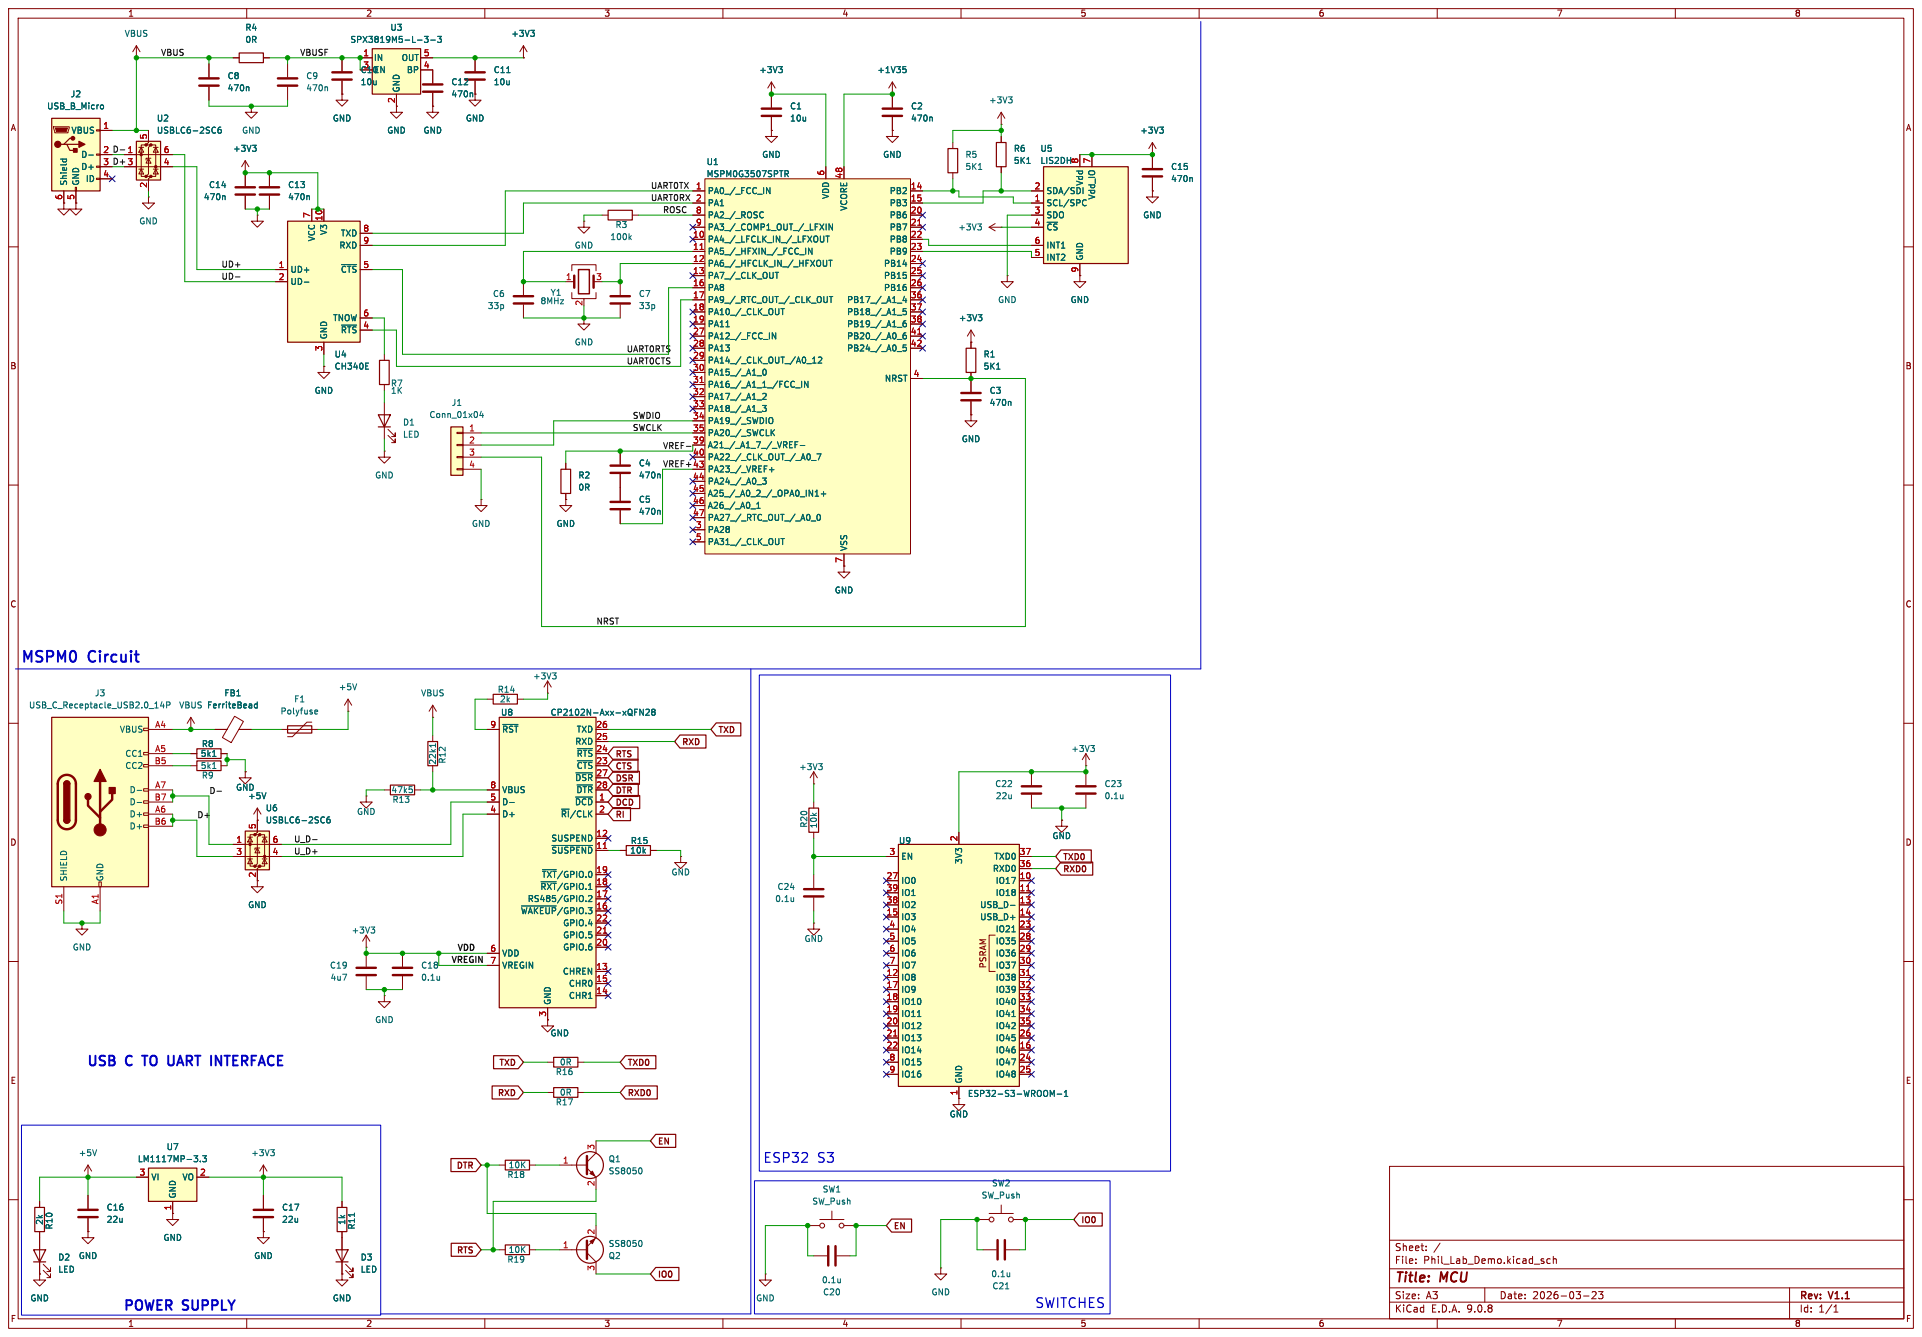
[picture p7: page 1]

+3V3 SDA/SDI 2 SCL/SPC 1 SDO 3 ~{CS} 4

SDA/SDI 2 SCL/SPC 1 SDO 3 ~{CS} 4

U_D- USB C TO UART INTERFACE

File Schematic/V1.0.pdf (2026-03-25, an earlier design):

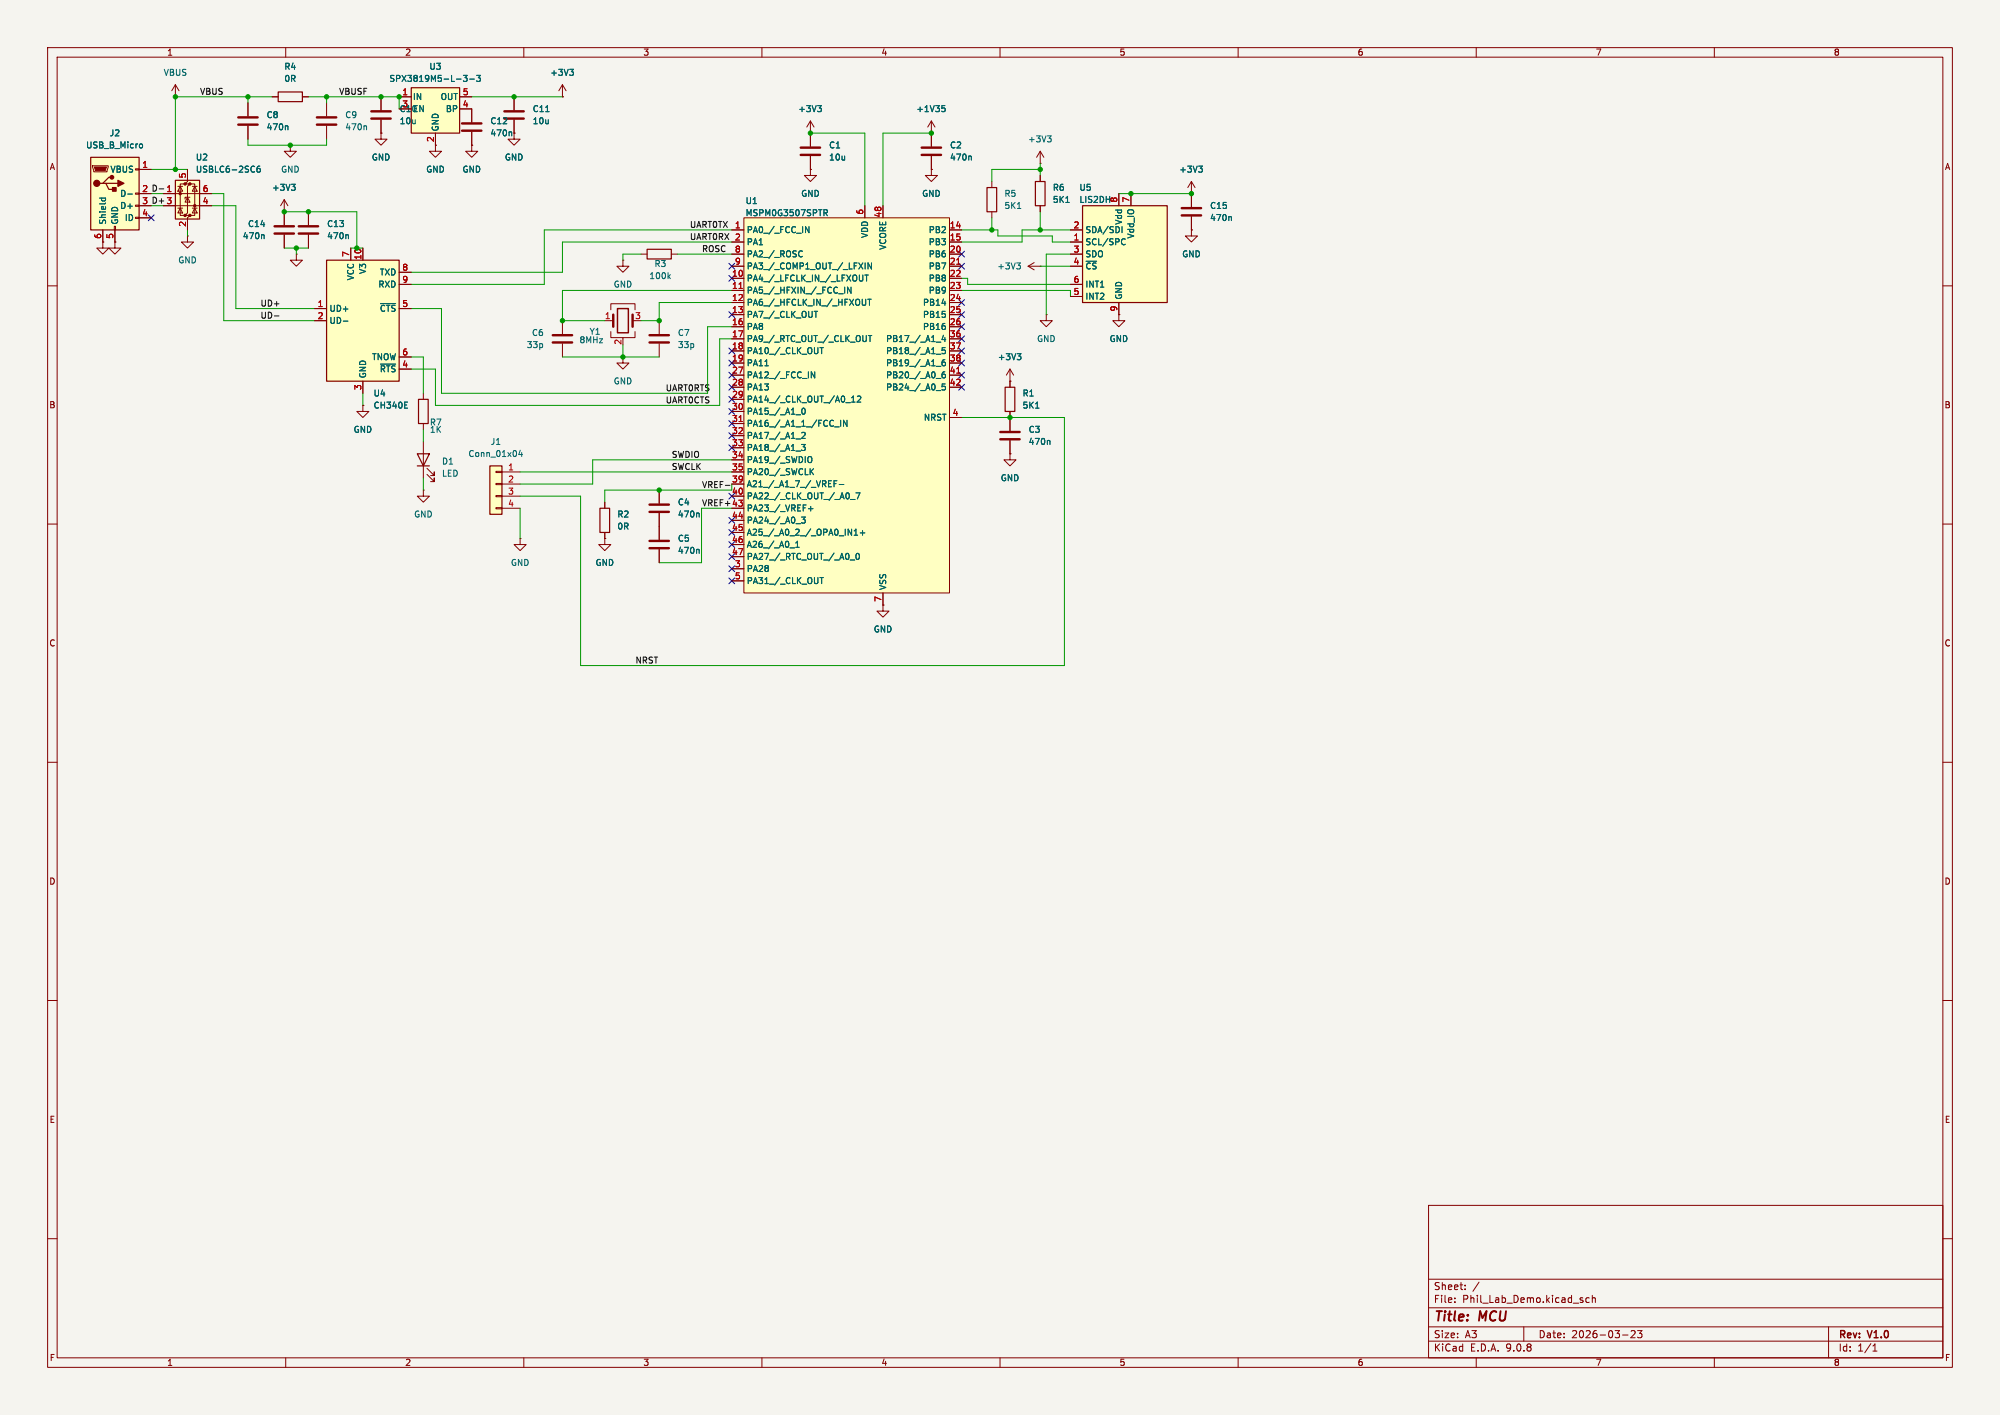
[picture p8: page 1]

3 TXD 8 RXD 9 ~{CTS}5 TNOW 6 ~{RTS}4 GND GND GND

3 TXD 8 RXD 9 ~{CTS}5 TNOW 6 ~{RTS}4 U4 CH340E

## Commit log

2026-04-05 uploading bom
    [Phil_Lab_Demo.csv]
2026-04-21 inclusion of the schematic
2026-04-21 updation of the bom
    [updated_bom_2.csv]
2026-07-30 changes to repo structure
    [BOM.csv, updated_bom_2.csv]
2026-08-01 changes to new board
    [Hades.kicad_pcb, Hades.kicad_sch]
2026-08-04 Revise HADES README with project details
    Updated README.md for HADES project with detailed information about its architecture, planned features, and current status.
2026-08-04 changes to the board
    [Battery.kicad_sch, Brain.kicad_sch, ESP32.kicad_sch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]
